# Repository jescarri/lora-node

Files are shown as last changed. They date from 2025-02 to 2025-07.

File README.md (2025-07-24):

# Lora Soil Moisture Sensor



This is a low-power, ESP32-powered LoRa board designed for general purposes. For this project, I used the board with a capacitive soil moisture sensor to monitor my houseplants.

# The build

This is a 4-layer PCB board that features a NICERF RFM95W for the LoRa radio and an ESP-WROOM-32D as the microcontroller. Two XC6220B301MR-G LDOs create two separate power rails at 3.0V.

The first power rail supplies power exclusively to the microcontroller (MCU), while the second rail serves as an instrumentation line that becomes active when the ESP32 wakes up from deep sleep. This rail powers both the radio and the sensors. Additionally, the MAX17048 includes a LiPo fuel gauge.

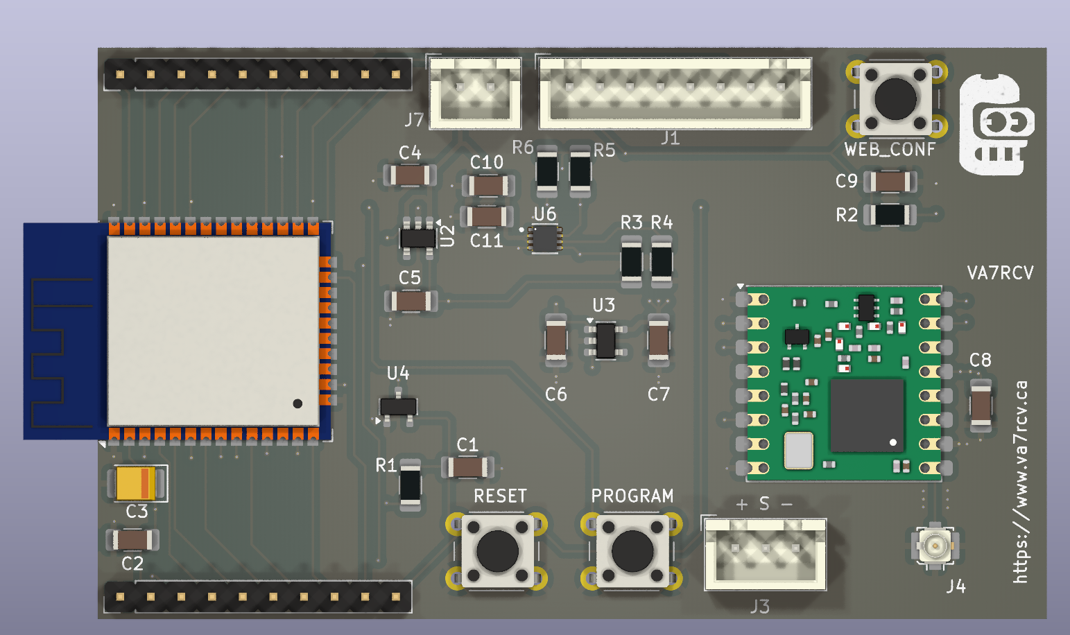
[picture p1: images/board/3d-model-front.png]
Board Front


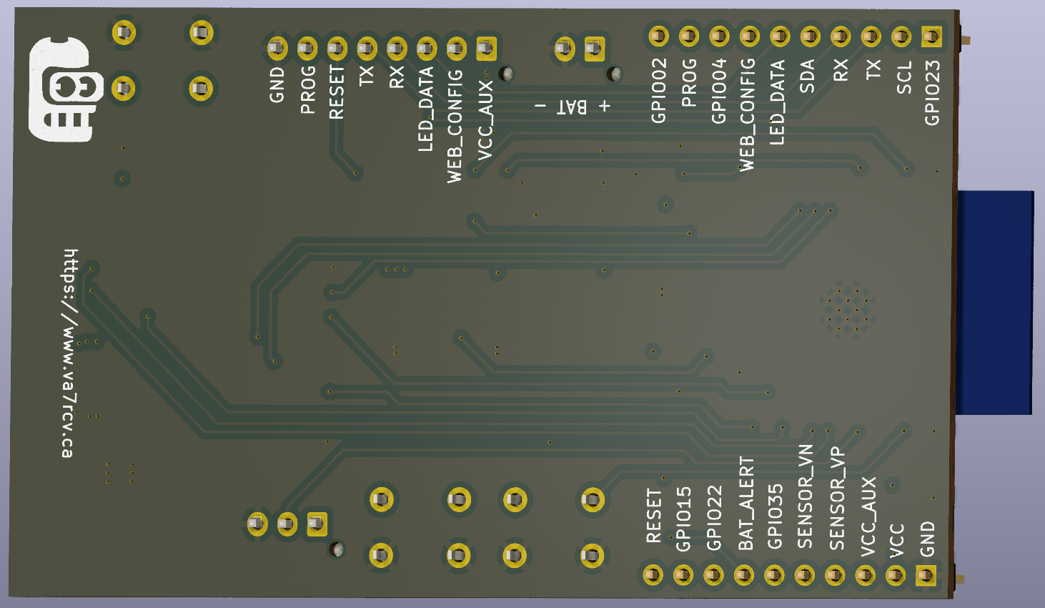
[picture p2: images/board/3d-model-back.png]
Board Back


There's a WS2812B LED that provides feedback to the user.

- Red: The node does not have a valid configuration or is in WebConfig state (AP Mode).

- Green: Node successfully joined TTN after configuration.

- Orange: Error Joining the TTN network.

- Unless the above events happen, the LED remains powered off at all times.

# The Firmware

The Lora deep sleep routines are based on [Andreas Spiess Lora Mailbox with DeepSleep](https://github.com/SensorsIot/MailboxNotifier/tree/main), but instead of using the EEPROM routines to save the LMIC status, I used the [Preferences library](https://docs.espressif.com/projects/arduino-esp32/en/latest/tutorials/preferences.html)

This project uses the ArduinoLMICC library.

This Firmware has a lot of debug code and requires some re-organization it is a PoC and it has been running for about 3 moths without any issue.

ToDo:
----

1. Add downlink capabilities to trigger WiFi join and do OTA.

2. Investigate how to add crypto validation of the firmware.

3. Re organize the code, WiFi menu and config is a mess.

4. Remove debug code.

5. Standardize LED feedback colors.

# Telemetry format

Data is sent to the Things Network using CayenneLPP, This project uses the [electroniccats/CayenneLPP][https://github.com/ElectronicCats/CayenneLPP] implementation, I found this to be the implementation that had extended support for extra data fields.

# Things Network configuration

1. Create an application.

2. Add the Payload Decoder from the (electroniccats/CayenneLPP)[] project.

3. Create an device use: LoRaWAN Specification 1.0.3, RP001 Regional Parameters 1.0.3 revision A

# Build Configuration and Size Optimization

This project uses a single optimized build configuration:

- **ttgo-lora32-v1-release**: Production build with size optimizations (-Os, function/data sections, dead code elimination)

## Size-Saving Tips

1. **String Storage**: Use PROGMEM for string constants to reduce SRAM usage
2. **Conditional Compilation**: Wrap diagnostic code with `#ifdef DEBUG` blocks for development
3. **Compiler Optimization**: Use `-Os`, `-ffunction-sections`, `-fdata-sections`, `-Wl,--gc-sections`
4. **LMIC Debug Level**: Set to 0 for production builds to reduce binary size

## Current Build Size

- **Release Build**: 92.4% Flash usage (1,211,449 bytes) - **90KB reduction achieved**

For detailed build information, see [docs/BUILD.md](docs/BUILD.md).

## Watchdog Management for OTA Updates

The firmware implements comprehensive watchdog timer management and stack overflow prevention to prevent system crashes during OTA (Over-The-Air) firmware updates:

### Watchdog Reset Points

- **WiFi Connection Loop**: Reset every 100ms during WiFi connection attempts (8-second timeout)
- **HTTP Download Loop**: Reset every 1000ms during firmware download (improved from 2000ms)
- **WiFi Test Function**: Reset every 400ms during WiFi connectivity testing
- **OTA Progress Updates**: Watchdog reset occurs with each progress update (every 5 seconds or 50KB chunks)

### Stack Overflow Prevention

To prevent stack canary watchpoint panics that can occur during OTA operations:

- **Heap-Allocated Download Buffer**: Uses `malloc()` to allocate a 2KB download buffer on the heap instead of stack
- **Reduced Buffer Size**: Download buffer reduced from 4KB to 2KB to minimize memory usage
- **Proper Error Cleanup**: All error paths properly free allocated memory with appropriate cleanup
- **Memory Safety**: Buffer is set to `nullptr` after freeing to prevent double-free issues

### Timeout Constants

- `WIFI_CONNECTION_TIMEOUT`: 8000ms (8 seconds) - Maximum time to wait for WiFi connection
- `HTTP_TOTAL_TIMEOUT`: 30000ms (30 seconds) - Total HTTP request timeout for OTA downloads
- `HTTP_CONNECT_TIMEOUT`: 15000ms (15 seconds) - HTTP connection establishment timeout
- `CONNECTIVITY_TEST_TIMEOUT`: 10000ms (10 seconds) - Internet connectivity test timeout
- `WATCHDOG_RESET_INTERVAL_DOWNLOAD`: 1000ms (1 second) - Watchdog reset frequency during download
- `WATCHDOG_RESET_INTERVAL_WIFI_TEST`: 400ms - Watchdog reset frequency during WiFi testing
- `PROGRESS_UPDATE_INTERVAL`: 5000ms (5 seconds) - Progress update and watchdog reset frequency
- `CHUNK_SIZE_THRESHOLD`: 51200 bytes (50KB) - Alternative trigger for progress updates

### HTTPUpdate Library Integration

The OTA system now uses ESP32's built-in HTTPUpdate library for improved reliability:

- **Automatic HTTPS Support**: Handles both HTTP and HTTPS URLs with redirect following
- **MD5 Verification**: Uses HTTPUpdate's native MD5 verification with manual header injection
  - GitHub doesn't provide `x-MD5` headers, so we inject the MD5 from TTN downlink via request callback
  - HTTPUpdate then performs automatic MD5 verification during download
- **Progress Monitoring**: Real-time download progress with watchdog management
- **Error Handling**: Comprehensive error reporting and cleanup
- **Memory Efficiency**: No large buffer allocation - HTTPUpdate handles streaming internally
- **Redirect Support**: Automatic handling of HTTP redirects (strict mode enabled)

### Network Diagnostics

The OTA system includes comprehensive network diagnostics:

- **HTTPS Support**: Automatic detection and handling of HTTPS URLs with certificate validation bypass
- **Timeout Configuration**: Explicit HTTP timeouts prevent indefinite blocking
- **Redirect Handling**: Automatic following of HTTP redirects using HTTPUpdate's built-in support
- **Error Reporting**: Detailed error codes and diagnostic messages for troubleshooting

## Build Commands

- `make release`: Build the main release environment (ttgo-lora32-v1)
- `make minimal`: Build the minimal environment for comparison
- For verbose output, set environment variable: `PLATFORMIO_BUILD_FLAGS=-v`
  
  Example: `PLATFORMIO_BUILD_FLAGS=-v make release`

# Node Provisioning

1. Build the firmware and upload it to the board.

2. The board will enter in config mode, and access point named lora-node will be created.

3. Connect to the wifi and open 192.168.4.1 in your web browser, and configure the node paramethers.

3.1 Provisioning Menu:

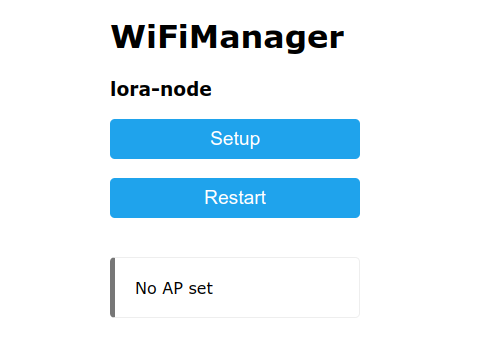
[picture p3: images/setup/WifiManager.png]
Wifi Manager WiFi Manager


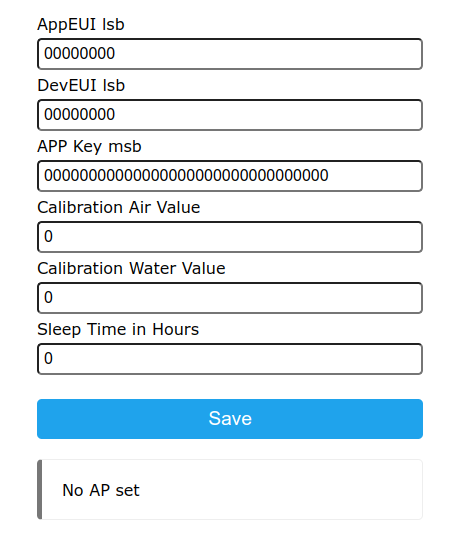
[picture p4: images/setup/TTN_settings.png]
TTN and Calibration Settings


# Soil moisture sensor calibration

Once the node is provisioned, and joined your applicaton in The things network.

1. Rested the board and measure the reading in Air-Free / Dry conditions and record raw sensore reading, you can see it in the serial console or in TTN.

2. Submerge the soil sensor in water and reset the board and record the raw sensor reading.

3. Press the WEB_CONF button and reset the board leaving the WEB_CONF button pressed, the board will enter in configuration mode and a WiFi Access point named lora-node will appear, connect to it and go to 192.168.4.1 in your browser.

4. Input the Free-Air and Water values recorded in steps 1 and 2.

Calibration is done.

# Home Assistant Integration

You need to configure an MQTT bridge between TTN and your Local MQTT server, there's plenty of information on how to do this online.

The Node-Red folder has Auto-Discovery, that you can use as a starting point for MQTT auto discovery.

There's also a Telegram bot that will notify you when the Node has not been seen in 24 Hours.

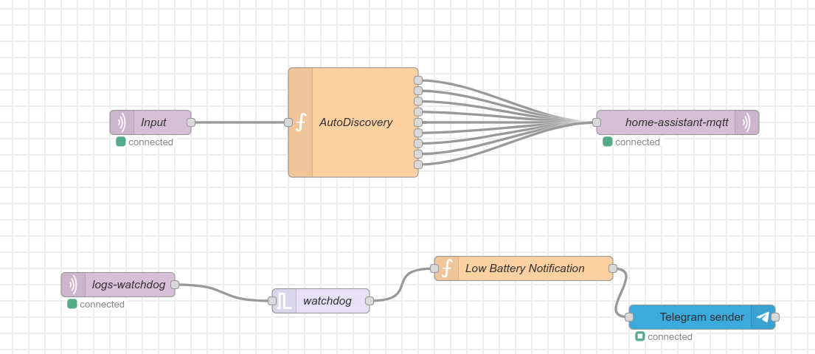
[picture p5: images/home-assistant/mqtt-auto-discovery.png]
MQTT Autodiscovery Home Assistant MQTT Autodiscovery


MQTT Device
-----------

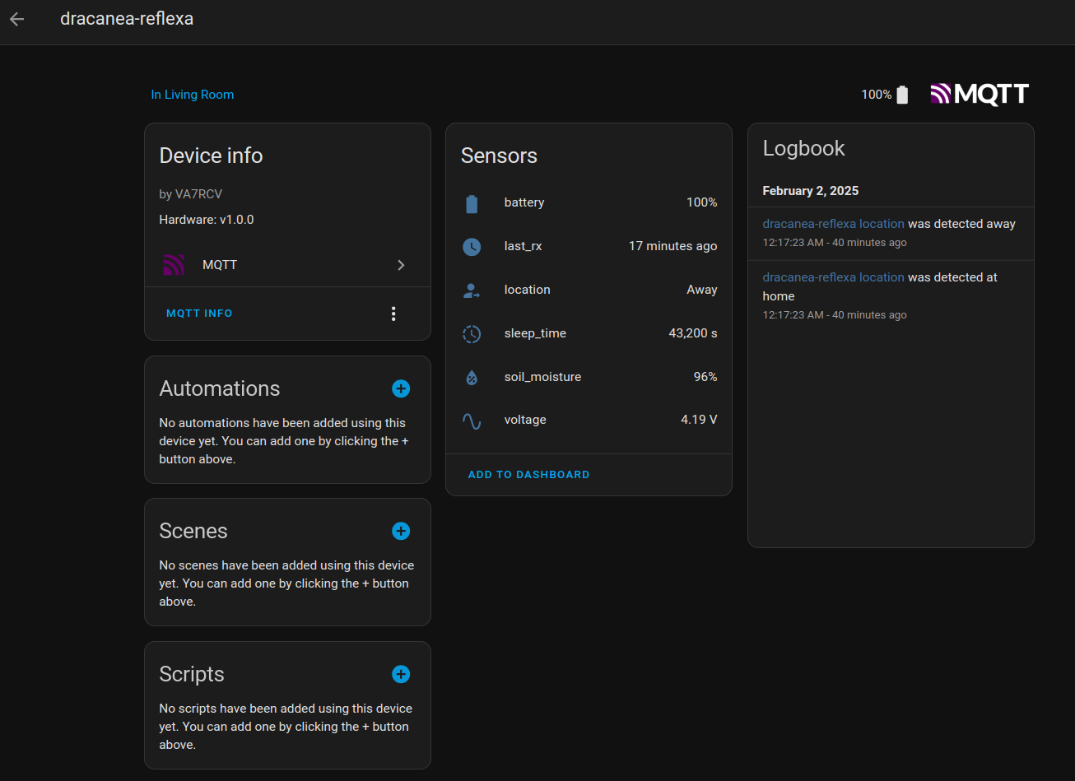
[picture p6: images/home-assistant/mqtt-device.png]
MQTT Device


Home assistant Panel
------------------

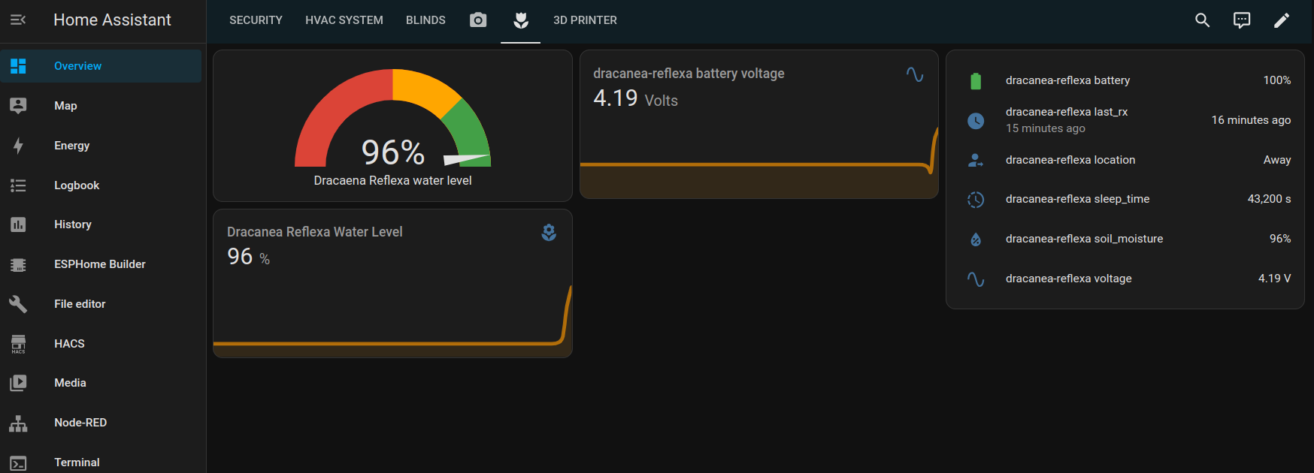
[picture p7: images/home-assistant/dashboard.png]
HA Panel


# Enclosure

Under the enclosure directory you will find STL files to print the sensor enclosure, you can 3D print the board holder and it will fit a 2.5 Inches PVC Pipe ( Internal Diameter ).

There's also a 3D model of a pipe you can print for indoors applications.

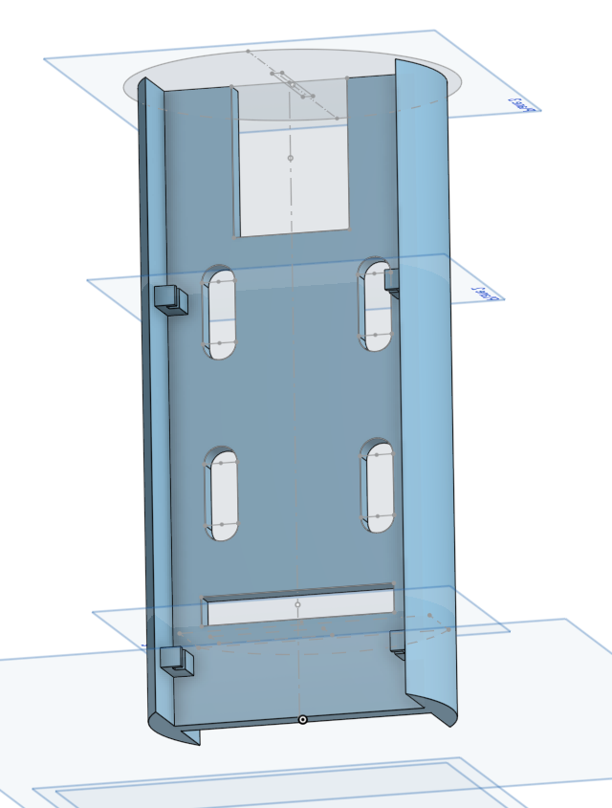
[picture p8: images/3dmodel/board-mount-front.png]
Board Holder


# Final Product

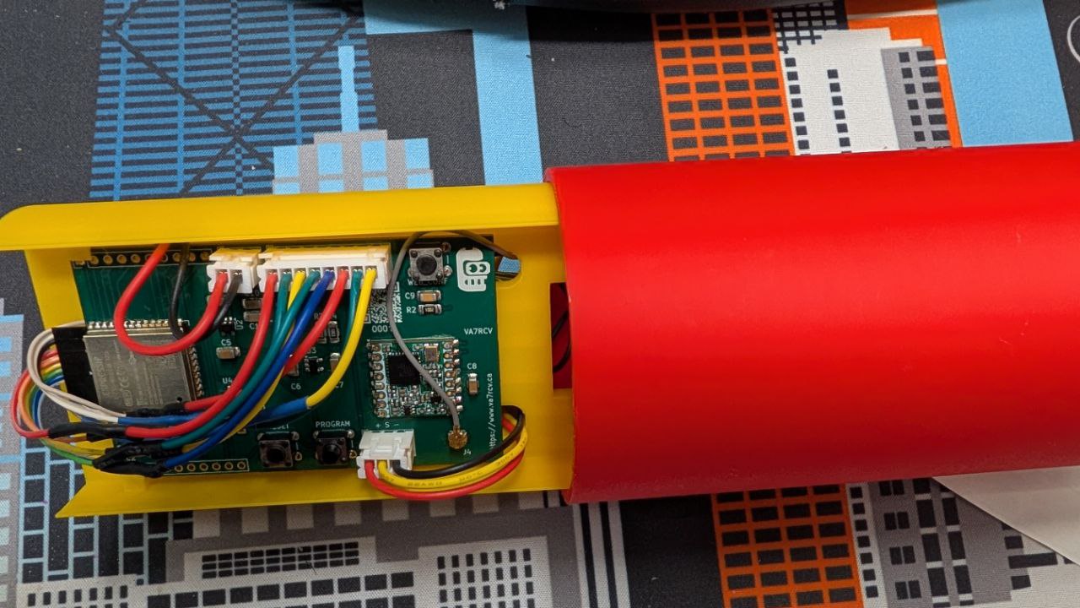
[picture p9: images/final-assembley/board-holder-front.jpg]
Board Front


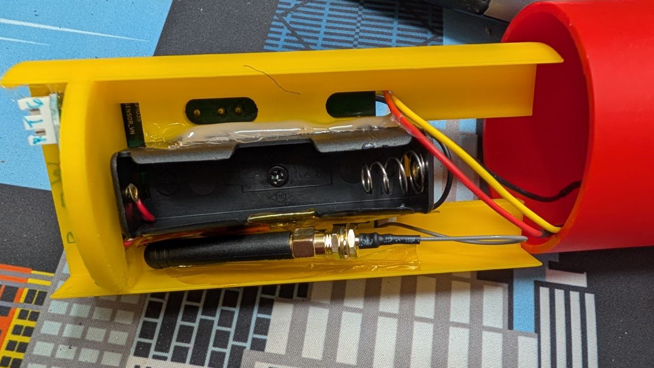
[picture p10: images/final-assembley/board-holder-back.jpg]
Board Back Board Holder Back


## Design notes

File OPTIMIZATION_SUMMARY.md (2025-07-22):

# String Storage and Logging Optimizations

## Overview
This document summarizes the string storage and logging optimizations applied to the LoRa sensor codebase to reduce memory usage and improve performance.

## 1. PROGMEM String Constants

### Files Modified:
- `src/main.cpp`
- `src/lorawan.cpp`

### Changes Made:
- Added `const char PROGMEM` declarations for frequently used string literals
- Replaced direct string literals with `FPSTR()` macro calls
- Used `F()` macro for inline string literals in Serial.print() calls

### Examples:
```cpp
// Before:
Serial.println("LIPO GAUGE FOUND");

// After:
const char PROGMEM msg_lipo_gauge_found[] = "LIPO GAUGE FOUND";
Serial.println(FPSTR(msg_lipo_gauge_found));

// Or alternatively:
Serial.println(F("LIPO GAUGE FOUND"));
```

### Benefits:
- Strings are stored in program memory (PROGMEM) instead of RAM
- Reduces SRAM usage during runtime
- Improves overall memory efficiency

## 2. Conditional Debug Compilation

### Files Modified:
- `platformio.ini`
- `src/main.cpp`
- `src/lorawan.cpp`

### Changes Made:
- Added conditional compilation using `#ifdef DEBUG` blocks for development diagnostics
- Applied conditional compilation to verbose logging functions

### Examples:
```cpp
// Before:
Serial.println("Debug message");

// After:
#ifdef DEBUG
Serial.println("Debug message");
#endif
```

### Benefits:
- Diagnostic logs can be selectively compiled during development
- Production builds have reduced code size
- Maintains debugging capability when needed for development

## 3. Optimized Logging Functions

### Changes Made:
- Modified `LoraWANDebug()` function to only execute in debug builds
- Replaced `Serial.printf()` with multiple `Serial.print()` calls for PROGMEM compatibility
- Optimized sensor reading debug output

### Benefits:
- Reduced flash memory usage in production builds
- Maintained debugging capabilities for development
- Improved code readability and maintainability

## 4. Build Size Results

### Release Build (ttgo-lora32-v1):
- Text: 1,069,553 bytes
- Data: 252,209 bytes
- BSS: 29,536 bytes
- **Total: 1,351,298 bytes**

### Optimizations Applied:
1. **String Storage**: Moved string constants to PROGMEM
2. **Conditional Compilation**: Added DEBUG flag for optional logging
3. **Memory Efficiency**: Reduced SRAM usage by storing strings in flash

## 5. Build Configuration

### Environment:
- **ttgo-lora32-v1-release**: Optimized production build with size optimizations

### Compilation Flags:
- `-Os`: Optimize for size
- `-ffunction-sections`: Place functions in separate sections
- `-fdata-sections`: Place data in separate sections
- `-Wl,--gc-sections`: Remove unused sections during linking

## 6. Testing

### Verification Steps:
1. ✅ Release build compiles successfully
2. ✅ String optimizations applied correctly
3. ✅ Conditional compilation works as expected
4. ✅ Memory usage reduced without functionality loss

## Summary

The optimizations successfully:
- Reduced memory usage by moving strings to PROGMEM
- Implemented conditional compilation for development diagnostics
- Maintained code functionality and readability
- Consolidated to a single optimized build configuration

These optimizations help improve the performance and memory efficiency of the LoRa sensor device, especially important for embedded systems with limited resources.

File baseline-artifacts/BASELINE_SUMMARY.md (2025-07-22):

# Size-Tracking Baseline - Task Completion Summary

## ✅ Task Completed Successfully

This document summarizes the completion of **Step 1: Create a size-tracking baseline** from the project optimization plan.

## What Was Accomplished

### 1. ✅ Clean Build Locally
- Performed a clean build using `pio run -v > build.log`
- Captured detailed build output with memory usage information
- Recorded current memory usage:
  - **RAM**: 17.3% (56,560 bytes used / 327,680 bytes total)
  - **Flash**: 99.3% (1,302,037 bytes used / 1,310,720 bytes total)

### 2. ✅ Captured .elf and .map Files
- Generated and archived `firmware.elf` (20.2 MB)
- Generated and archived `firmware.map` (13.8 MB)
- Both files are now preserved in the `baseline-artifacts/` directory

### 3. ✅ Recorded Flash/RAM Usage
- Created comprehensive memory usage summary in `memory-usage-summary.txt`
- Detailed build log with verbose output shows memory sections
- Identified that Flash memory is nearly full (99.3%), highlighting optimization need

### 4. ✅ GitHub CI Runner Setup
- Created `.github/workflows/size-baseline.yml` workflow
- Configured to trigger on pushes to `size-baseline` branch
- Will capture the same artifacts on GitHub Actions ubuntu-latest runners
- CI artifacts will be uploaded with 90-day retention

### 5. ✅ Committed to size-baseline Branch
- Created new branch `size-baseline` from current state
- Committed all baseline artifacts:
  - `firmware.elf` - Complete firmware binary
  - `firmware.map` - Memory map for detailed analysis
  - `build.log` - Verbose build output (forced add despite .gitignore)
  - `memory-usage-summary.txt` - Human-readable summary
- Pushed branch to origin to trigger CI workflow

## Files Archived for Later Diffing

| File | Size | Purpose |
|---|---|---|
| `firmware.elf` | 20.2 MB | Complete firmware binary with debug symbols |
| `firmware.map` | 13.8 MB | Memory map showing symbol locations and sizes |
| `build.log` | 159 KB | Verbose build output with memory section details |
| `memory-usage-summary.txt` | 856 B | Human-readable summary of memory usage |

## Critical Measurements Captured

- **Current RAM Usage**: 56,560 bytes (17.3% of 327,680 bytes)
- **Current Flash Usage**: 1,302,037 bytes (99.3% of 1,310,720 bytes)
- **Available Flash**: Only 8,683 bytes remaining (0.7%)
- **Build Environment**: ttgo-lora32-v1 (ESP32)
- **Git Commit**: faae3e0d8deeaebde633c6fe64fd03a4eff1e3f5

## Next Steps

This baseline provides the foundation for objective measurement of all future optimization steps. Each subsequent step can now be measured against this baseline using:

1. **Memory Usage Comparison**: Compare RAM/Flash percentages
2. **Map File Diffing**: Use `firmware.map` to identify which symbols/sections changed
3. **Build Log Analysis**: Compare verbose build outputs to track compilation changes
4. **Automated CI Tracking**: GitHub Actions will capture equivalent baselines

## Usage Instructions

To compare future builds against this baseline:

```bash
# Compare memory usage
grep "RAM:\|Flash:" baseline-artifacts/build.log
grep "RAM:\|Flash:" current-build.log

# Diff memory maps
diff baseline-artifacts/firmware.map .pio/build/ttgo-lora32-v1/firmware.map

# Compare ELF files
size baseline-artifacts/firmware.elf
size .pio/build/ttgo-lora32-v1/firmware.elf
```

The size-baseline branch is now ready for use as the reference point for all future optimization measurements.

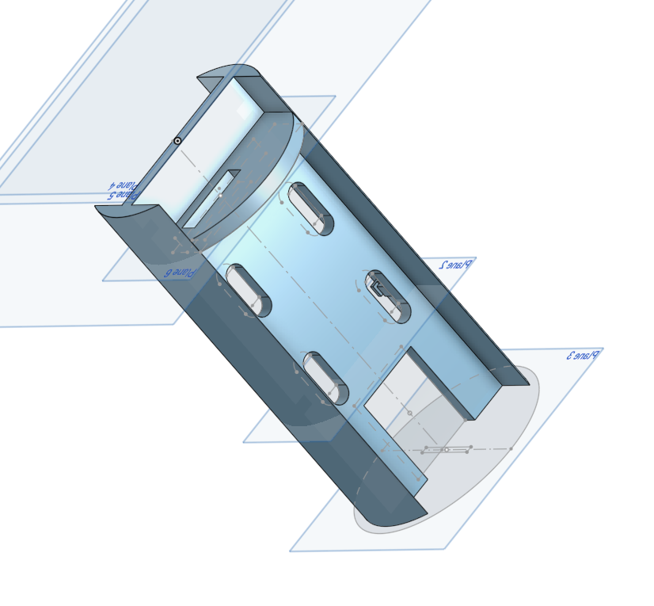
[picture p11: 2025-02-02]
images/3dmodel/board-mount-side.png

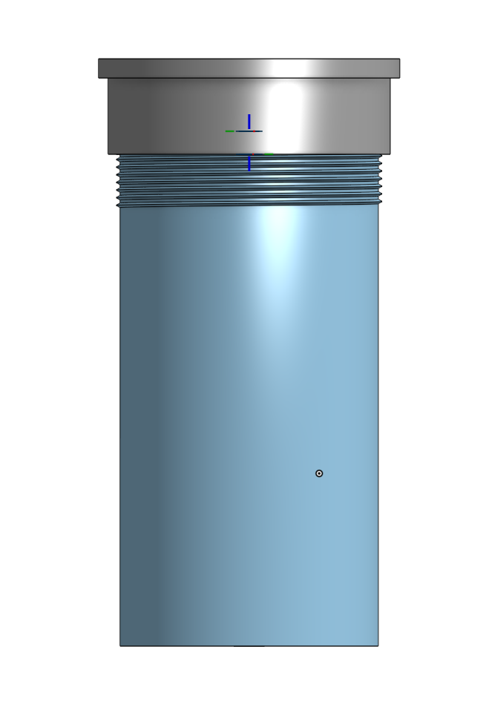
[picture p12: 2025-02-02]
images/3dmodel/tube.png

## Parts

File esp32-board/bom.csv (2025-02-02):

Reference | Value | Datasheet | Footprint | Qty | DNP
C1,C9 | 1uF | ~ | Capacitor_SMD:C_1206_3216Metric_Pad1.33x1.80mm_HandSolder | 2
C2,C10,C11 | 100nF | ~ | Capacitor_SMD:C_1206_3216Metric_Pad1.33x1.80mm_HandSolder | 3
C3 | 22uF | ~ | Capacitor_Tantalum_SMD:CP_EIA-3528-21_Kemet-B_Pad1.50x2.35mm_HandSolder | 1
C4,C6,C8 | 10uF | ~ | Capacitor_SMD:C_1206_3216Metric_Pad1.33x1.80mm_HandSolder | 3
C5,C7 | 4.7uF | ~ | Capacitor_SMD:C_1206_3216Metric_Pad1.33x1.80mm_HandSolder | 2
J1 | remote_header | ~ | Connector_JST:JST_XH_B8B-XH-AM_1x08_P2.50mm_Vertical | 1
J3 | SOIL_SENSOR | ~ | Connector_JST:JST_XH_B3B-XH-AM_1x03_P2.50mm_Vertical | 1
J4 | ANT | ~ | Connector_Coaxial:U.FL_Molex_MCRF_73412-0110_Vertical | 1
J5,J6 | Conn_01x10_Pin | ~ | Connector_PinHeader_2.54mm:PinHeader_1x10_P2.54mm_Vertical | 2
J7 | Battery | ~ | Connector_JST:JST_XH_B2B-XH-AM_1x02_P2.50mm_Vertical | 1
R1,R2,R3 | 10K | ~ | Resistor_SMD:R_1206_3216Metric_Pad1.30x1.75mm_HandSolder | 3
R4 | 100k | ~ | Resistor_SMD:R_1206_3216Metric_Pad1.30x1.75mm_HandSolder | 1
R5,R6 | 2.2K | ~ | Resistor_SMD:R_1206_3216Metric_Pad1.30x1.75mm_HandSolder | 2
RESET1 | RESET | ~ | Button_Switch_THT:SW_PUSH_6mm_H5mm | 1
SW2 | ESP Program | ~ | Button_Switch_THT:SW_PUSH_6mm_H5mm | 1
SW3 | WEB_CONF | ~ | Button_Switch_THT:SW_PUSH_6mm_H5mm | 1
U1 | ESP32-WROOM-32D | https://www.espressif.com/sites/default/files/documentation/esp32-wroom-32d_esp32-wroom-32u_datasheet_en.pdf | RF_Module:ESP32-WROOM-32 | 1
U2,U3 | XC6220B331MR | https://www.torexsemi.com/file/xc6220/XC6220.pdf | Package_TO_SOT_SMD:SOT-23-5 | 2
U4 | TPS3839DBZ | http://www.ti.com/lit/ds/sbvs193d/sbvs193d.pdf | Package_TO_SOT_SMD:SOT-23 | 1
U5 | RFM95W-915S2 | https://www.hoperf.com/data/upload/portal/20181127/5bfcbea20e9ef.pdf | RF_Module:HOPERF_RFM9XW_SMD | 1
U6 | MAX17048G_T10 |  | MAX17048G+T10:SON50P200X200X80-9N | 1

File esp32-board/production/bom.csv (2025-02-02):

Designator | Footprint | Quantity | Value | LCSC Part #
C1, C9 | 1206 | 2 | 1uF
C10, C11, C2 | 1206 | 3 | 100nF
C3 | CP_EIA-3528-21_Kemet-B_Pad1.50x2.35mm_HandSolder | 1 | 22uF
C4, C6, C8 | 1206 | 3 | 10uF
C5, C7 | 1206 | 2 | 4.7uF
J1 | JST_XH_B8B-XH-AM_1x08_P2.50mm_Vertical | 1 | remote_header
J3 | JST_XH_B3B-XH-AM_1x03_P2.50mm_Vertical | 1 | SOIL_SENSOR
J4 | U.FL_Molex_MCRF_73412-0110_Vertical | 1 | ANT
J5, J6 | PinHeader_1x10_P2.54mm_Vertical | 2 | Conn_01x10_Pin
J7 | JST_XH_B2B-XH-AM_1x02_P2.50mm_Vertical | 1 | Battery
R1, R2, R3 | 1206 | 3 | 10K
R4 | 1206 | 1 | 100k
R5, R6 | 1206 | 2 | 2.2K
RESET1 | SW_PUSH_6mm_H5mm | 1 | RESET
SW2 | SW_PUSH_6mm_H5mm | 1 | ESP Program
SW3 | SW_PUSH_6mm_H5mm | 1 | WEB_CONF
U1 | ESP32-WROOM-32 | 1 | ESP32-WROOM-32D
U2, U3 | SOT-23-5 | 2 | XC6220B331MR
U4 | SOT-23 | 1 | TPS3839DBZ
U5 | HOPERF_RFM9XW_SMD | 1 | RFM95W-915S2
U6 | SON50P200X200X80-9N | 1 | MAX17048G_T10

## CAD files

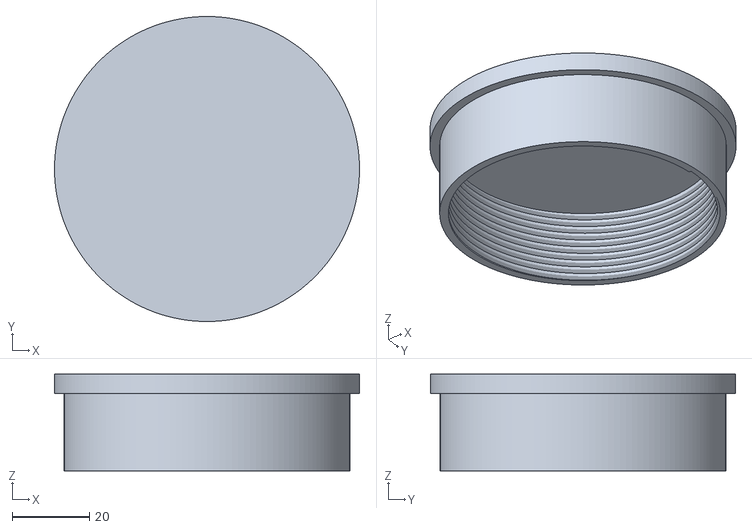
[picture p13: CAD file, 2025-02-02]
enclosure/cap.stl
79.0 x 79.0 x 25.0

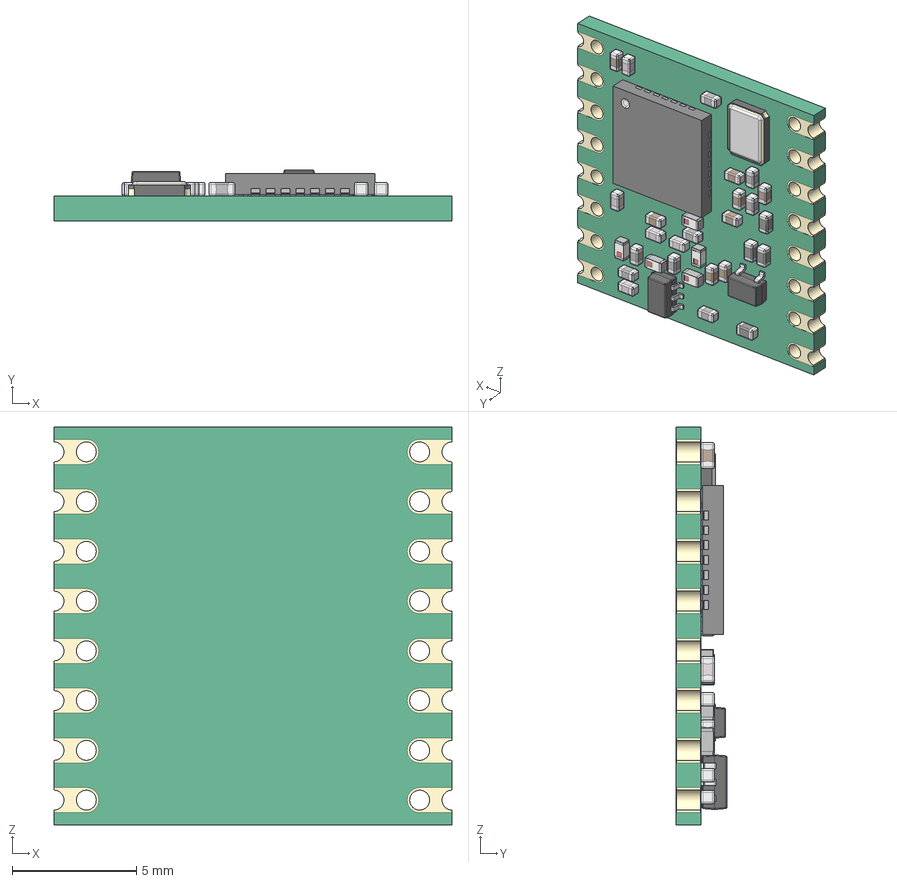
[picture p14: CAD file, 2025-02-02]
esp32-board/models/RFM95/RFM95 LoRa v15.step
16.0 x 2.04 x 16.0 mm
QFN 28
SMD Crystal
CAP 0403 x 8
CAP Ceramic 0403 x 8
Res 0403 x 4
CAP ML 0403 x 5
SOT-323
Inductor SMD 0403 x 5
SOT-363

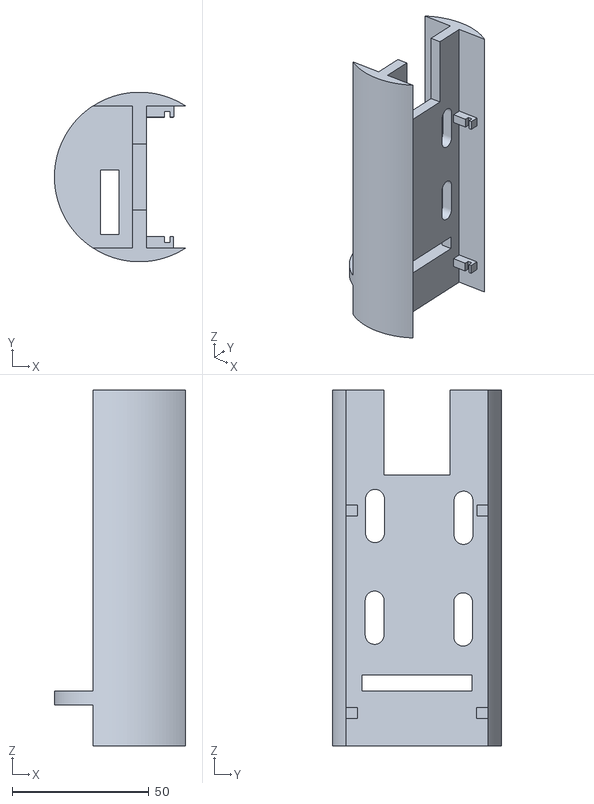
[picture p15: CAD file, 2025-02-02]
enclosure/board-mount.stl
47.9 x 61.9 x 130.0

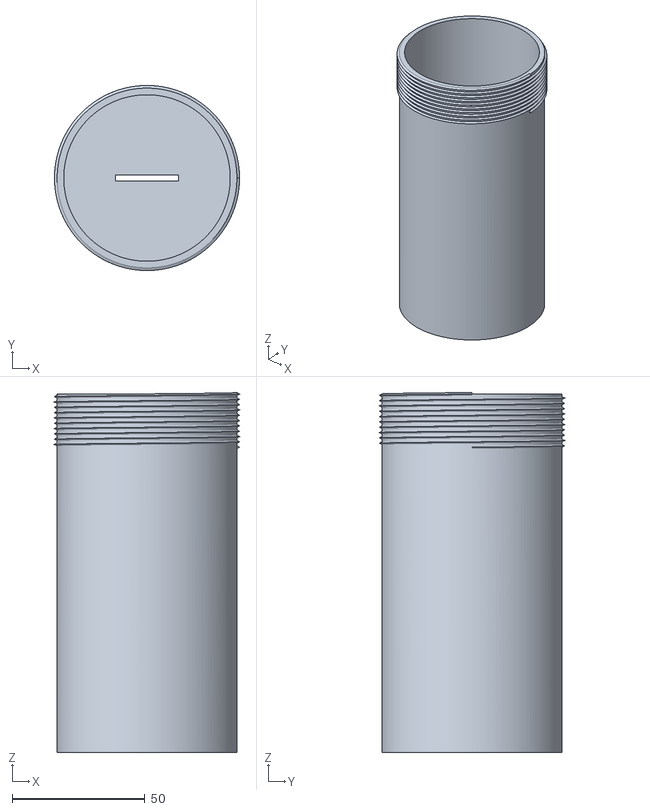
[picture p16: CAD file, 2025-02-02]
enclosure/tube.stl
69.7 x 69.7 x 135.6

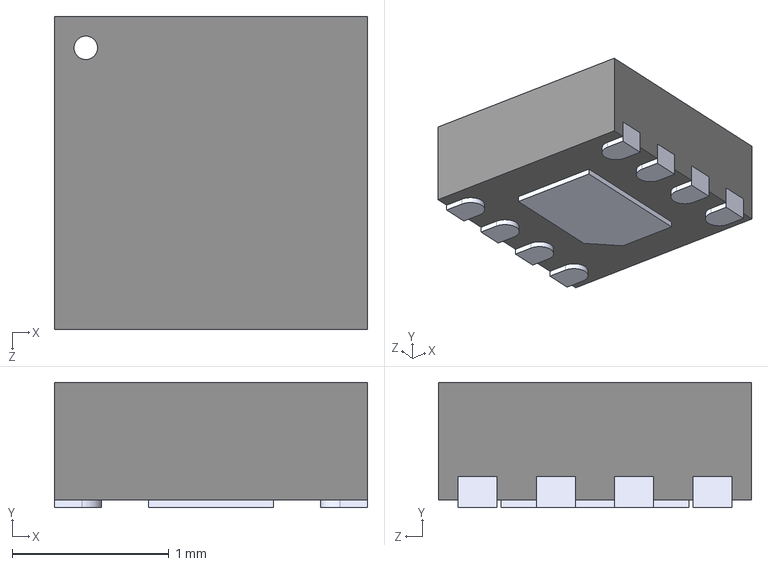
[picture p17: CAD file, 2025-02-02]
esp32-board/models/MAX17048G+T10/MAX17048G_T10.step
2.00 x 0.8 x 2.00 mm

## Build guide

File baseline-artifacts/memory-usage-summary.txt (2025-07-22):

Size Tracking Baseline - Memory Usage Summary
=============================================

Build Environment: ttgo-lora32-v1
Build Date: Wed 16 Jul 2025 12:56:56 PM PDT
Git Branch: size-baseline
Git Commit: faae3e0d8deeaebde633c6fe64fd03a4eff1e3f5

MEMORY USAGE:
- RAM:   17.3% (used 56,560 bytes from 327,680 bytes)
- Flash: 99.3% (used 1,302,037 bytes from 1,310,720 bytes)

AVAILABLE MEMORY:
- Free RAM: 271,120 bytes (82.7%)
- Free Flash: 8,683 bytes (0.7%)

FILES ARCHIVED:
- firmware.elf: Complete firmware binary
- firmware.map: Memory map file for analysis
- build.log: Verbose build output with detailed memory sections

USAGE:
This baseline can be used to compare memory usage changes in future builds.
Use the firmware.map file to analyze memory layout changes.
Compare build.log files to identify which components contribute to size changes.

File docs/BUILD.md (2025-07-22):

# Build Documentation

This document provides instructions and tips for building the firmware of the LoRa Soil Moisture Sensor project.

## Build Environment

- **ttgo-lora32-v1-release**: Production build with optimizations for size.

## Build Size Optimization Tips

1. **String Storage**: Store string constants in PROGMEM to reduce SRAM usage.
2. **Conditional Compilation**: Use DEBUG flags during development for diagnostic information.
3. **Compiler Flags**: Use `-Os`, `-ffunction-sections`, `-fdata-sections`, `-Wl,--gc-sections` to optimize for size.

## Current Build Size

- **Release Build**:
  - RAM: 16.8% (used 55,084 bytes from 327,680 bytes)
  - Flash: 92.4% (used 1,211,449 bytes from 1,310,720 bytes)

## Size Reduction

- **Before Optimization**:
  - Flash: 99.3% (used 1,302,037 bytes)

- **After Optimization**:
  - Flash: 92.4% (used 1,211,449 bytes)

- **Total Reduction**: 90,588 bytes (~14 KB)

## Building the Firmware

To build the firmware, use the following command:

```bash
pio run --environment ttgo-lora32-v1-release
```

## Skipping Size Checks

For development purposes, you may skip the size check:
```
extra_scripts = pre:skip_size_check.py
```

This concludes the build documentation.

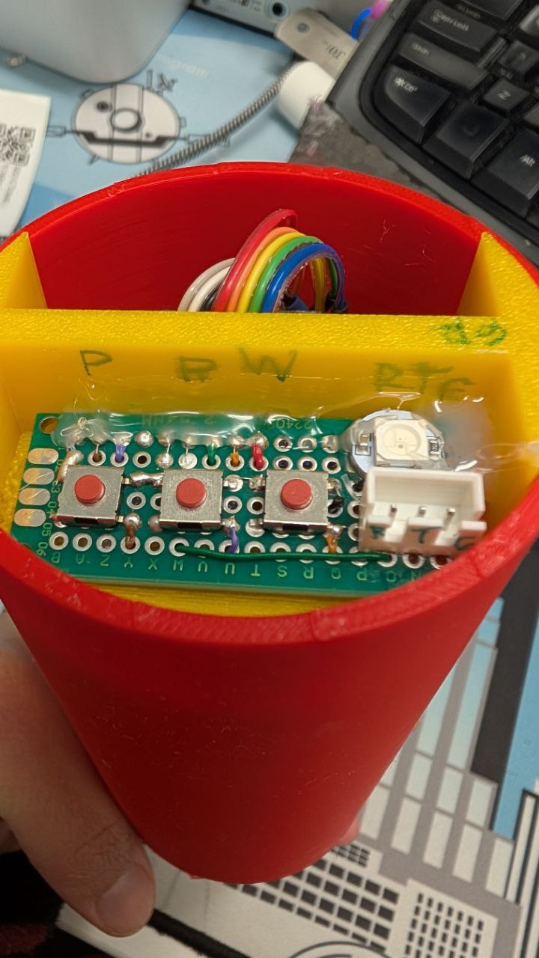
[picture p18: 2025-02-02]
images/final-assembley/control-board.jpg

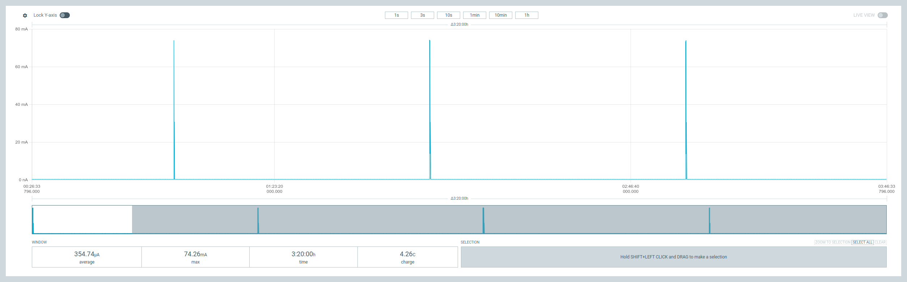
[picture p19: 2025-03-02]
power-profile/v1.0.0/3hours_of_operation.png

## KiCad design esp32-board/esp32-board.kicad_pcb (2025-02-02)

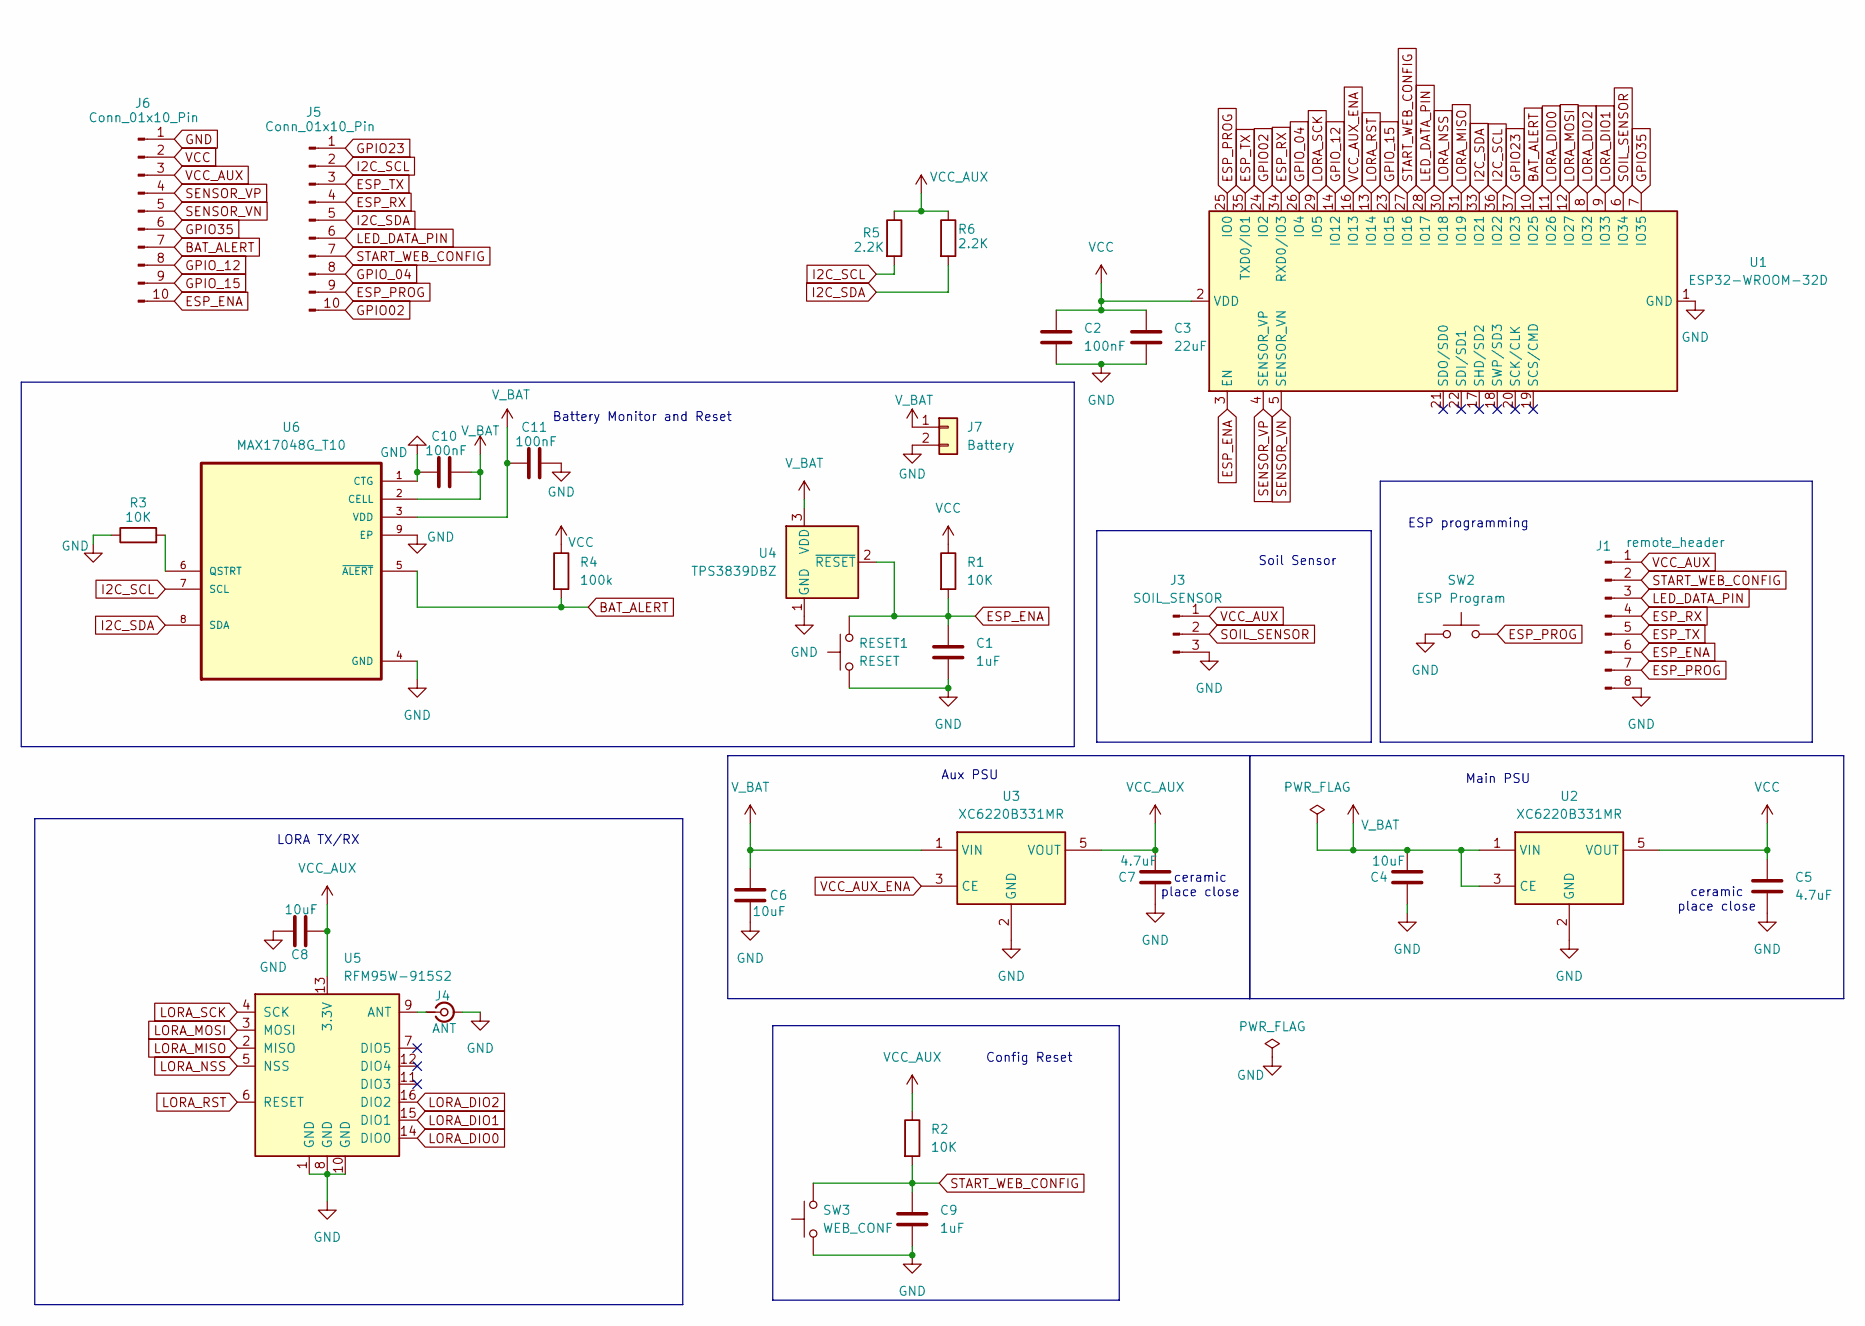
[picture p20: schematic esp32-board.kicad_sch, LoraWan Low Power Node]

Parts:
C1, C9: 1uF; C_1206_3216Metric_Pad1.33x1.80mm_HandSolder
C2, C10, C11: 100nF; C_1206_3216Metric_Pad1.33x1.80mm_HandSolder
C3: 22uF; CP_EIA-3528-21_Kemet-B_Pad1.50x2.35mm_HandSolder
C4, C6, C8: 10uF; C_1206_3216Metric_Pad1.33x1.80mm_HandSolder
C5, C7: 4.7uF; C_1206_3216Metric_Pad1.33x1.80mm_HandSolder
J1: remote_header; JST_XH_B8B-XH-AM_1x08_P2.50mm_Vertical
J3: SOIL_SENSOR; JST_XH_B3B-XH-AM_1x03_P2.50mm_Vertical
J4: ANT; U.FL_Molex_MCRF_73412-0110_Vertical
J5, J6: Conn_01x10_Pin; PinHeader_1x10_P2.54mm_Vertical
J7: Battery; JST_XH_B2B-XH-AM_1x02_P2.50mm_Vertical
R1, R2, R3: 10K; R_1206_3216Metric_Pad1.30x1.75mm_HandSolder
R4: 100k; R_1206_3216Metric_Pad1.30x1.75mm_HandSolder
R5, R6: 2.2K; R_1206_3216Metric_Pad1.30x1.75mm_HandSolder
RESET1: RESET; SW_PUSH_6mm_H5mm
SW2: ESP Program; SW_PUSH_6mm_H5mm
SW3: WEB_CONF; SW_PUSH_6mm_H5mm
U1: ESP32-WROOM-32D; ESP32-WROOM-32
U2, U3: XC6220B331MR; SOT-23-5
U4: TPS3839DBZ; SOT-23
U5: RFM95W-915S2; HOPERF_RFM9XW_SMD
U6: MAX17048G_T10; SON50P200X200X80-9N

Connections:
BAT_ALERT: J6.7, R4.2, U1.10 (IO25), U6.5 (~ALERT)
ESP_ENA: C1.1, J1.6, J6.10, R1.2, RESET1.2, U1.3 (EN), U4.2 (~RESET)
ESP_PROG: J1.7, J5.9, SW2.2, U1.25 (IO0)
ESP_RX: J1.4, J5.4, U1.34 (RXD0/IO3)
ESP_TX: J1.5, J5.3, U1.35 (TXD0/IO1)
GND: C1.2, C2.2, C3.2, C4.2, C5.2, C6.1, C7.2, C8.1, C9.2, C10.1, C11.2, J1.8, J3.3, J4.2 (Ext), J6.1, J7.2, R3.1, RESET1.1, SW2.1, SW3.1, U1.1 (GND), U1.15 (GND), U1.38 (GND), U1.39 (GND), U2.2 (GND), U3.2 (GND), U4.1 (GND), U5.1 (GND), U5.8 (GND), U5.10 (GND), U6.1 (CTG), U6.4 (GND), U6.9 (EP)
GPIO02: J5.10, U1.24 (IO2)
GPIO23: J5.1, U1.37 (IO23)
GPIO35: J6.6, U1.7 (IO35)
GPIO_04: J5.8, U1.26 (IO4)
GPIO_12: J6.8, U1.14 (IO12)
GPIO_15: J6.9, U1.23 (IO15)
I2C_SCL: J5.2, R5.2, U1.36 (IO22), U6.7 (SCL)
I2C_SDA: J5.5, R6.2, U1.33 (IO21), U6.8 (SDA)
LED_DATA_PIN: J1.3, J5.6, U1.28 (IO17)
LORA_DIO0: U1.11 (IO26), U5.14 (DIO0)
LORA_DIO1: U1.9 (IO33), U5.15 (DIO1)
LORA_DIO2: U1.8 (IO32), U5.16 (DIO2)
LORA_MISO: U1.31 (IO19), U5.2 (MISO)
LORA_MOSI: U1.12 (IO27), U5.3 (MOSI)
LORA_NSS: U1.30 (IO18), U5.5 (NSS)
LORA_RST: U1.13 (IO14), U5.6 (RESET)
LORA_SCK: U1.29 (IO5), U5.4 (SCK)
unnamed: J4.1 (In), U5.9 (ANT)
unnamed: R3.2, U6.6 (QSTRT)
SENSOR_VN: J6.5, U1.5 (SENSOR_VN)
SENSOR_VP: J6.4, U1.4 (SENSOR_VP)
SOIL_SENSOR: J3.2, U1.6 (IO34)
START_WEB_CONFIG: C9.1, J1.2, J5.7, R2.2, SW3.2, U1.27 (IO16)
VCC: C2.1, C3.1, C5.1, J6.2, R1.1, R4.1, U1.2 (VDD), U2.5 (VOUT)
VCC_AUX: C7.1, C8.2, J1.1, J3.1, J6.3, R2.1, R5.1, R6.1, U3.5 (VOUT), U5.13 (3.3V)
VCC_AUX_ENA: U1.16 (IO13), U3.3 (CE)
V_BAT: C4.1, C6.2, C10.2, C11.1, J7.1, U2.1 (VIN), U2.3 (CE), U3.1 (VIN), U4.3 (VDD), U6.2 (CELL), U6.3 (VDD)

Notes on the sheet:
ceramic place close
Config Reset
LORA TX/RX
Soil Sensor
ESP programming
Main PSU
Battery Monitor and Reset
Aux PSU

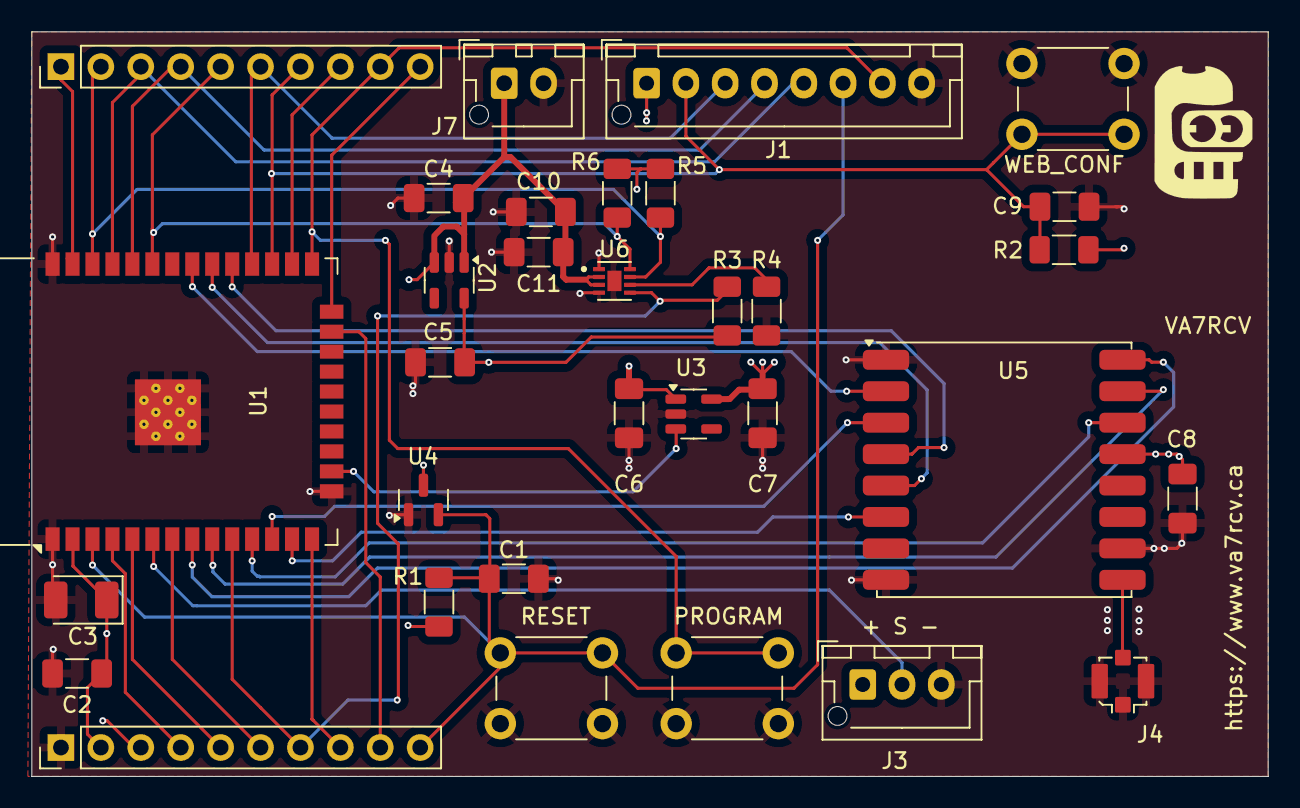
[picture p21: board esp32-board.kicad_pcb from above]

Board: 4 copper layers, 78.7 x 47.4 mm, 32 parts (0 on the bottom side), 33 nets.

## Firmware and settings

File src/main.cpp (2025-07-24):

#include "WiFi.h"
#include "driver/adc.h"

#include <lmic.h>

#include "esp_bt.h"
#include "esp_wifi.h"

#include "esp_sleep.h"
#include "lorawan.hpp"
#include "lorawan_settings.hpp"
#include "menu.hpp"
#include "version.hpp"
#include "ota.hpp"
#include <array>
#include <Adafruit_MAX1704X.h>
#include <FastLED.h>
#include <Wire.h>
#include <hal/hal.h>

// PROGMEM string constants
const char PROGMEM msg_lipo_gauge_found[]    = "LIPO GAUGE FOUND";
const char PROGMEM msg_no_max14048[]         = "No MAX14048 found";
const char PROGMEM msg_lmic_config_present[] = "LMIC CONFIG Present: ";
const char PROGMEM msg_webconf_status[]      = "Webconf status: ";
const char PROGMEM msg_otaa_config_done[]    = "otaa_config_done: ";
const char PROGMEM msg_sleeping_for[]        = "Sleeping for: ";
const char PROGMEM msg_seconds[]             = " seconds";
const char PROGMEM msg_lmic_data_found[]     = "LMIC Data found";
const char PROGMEM msg_can_go_sleep[]        = "Can go sleep ";
const char PROGMEM msg_cannot_sleep[]        = "Cannot sleep ";
const char PROGMEM msg_time_critical_jobs[]  = "TimeCriticalJobs: ";
const char PROGMEM msg_runtime[]             = "Runtime: ";
const char PROGMEM msg_going_to_deepsleep[]  = "Going to DeepSleep for: ";
const char PROGMEM msg_go_deepsleep[]        = "Go DeepSleep";
const char PROGMEM msg_ota_in_progress[]     = "OTA in progress - preventing deep sleep";
const char PROGMEM msg_waiting_for_ota[]     = "Waiting for OTA to complete...";

constexpr int VCC_ENA_PIN                   = 13;
constexpr int START_WEB_CONFIG_PIN          = 16;
constexpr int NUM_LEDS                      = 1;
constexpr int LED_DATA_PIN                  = 17;
constexpr unsigned long long uS_TO_S_FACTOR = 1000000ULL;

lmic_t SETTINGS_LMIC;
CayenneLPP lpp(MAX_PAYLOAD_SIZE);
Adafruit_MAX17048 maxlipo;
CRGB leds[NUM_LEDS];
bool maxLipoFound = false;

// Active in LOW, normal operation is HIGH
bool startWebConfig = false;

void PrintRuntime();
void GoDeepSleep();
void ReadSensors();

volatile bool enableSleep_ = true;
unsigned long entry;

osjob_t sendjob;

const lmic_pinmap lmic_pins = {
    .nss            = config::PinLmicNss,
    .rxtx           = LMIC_UNUSED_PIN,
    .rst            = config::PinLmicRst,
    .dio            = {config::PinLmicDio0, config::PinLmicDio1, config::PinLmicDio2},
    .rxtx_rx_active = 0,
    .spi_freq       = 8000000,
};

static constexpr std::array<gpio_num_t, 12> AUX_PINS = {
    /* LoRa radio (SX127x) */
    GPIO_NUM_5,         // SS  (leave even if NC – harmless)
    GPIO_NUM_18,        // SCK / NSS
    GPIO_NUM_19,        // MISO
    GPIO_NUM_23,        // MOSI

    GPIO_NUM_14,        // RESET
    GPIO_NUM_26,        // DIO0
    GPIO_NUM_27,
    GPIO_NUM_33,        // DIO1
    GPIO_NUM_32,        // DIO2
    /* I²C battery gauge */
    GPIO_NUM_21,        // SDA
    GPIO_NUM_22,        // SCL
    GPIO_NUM_4          // MAX17048 ALRT
};

// Schedule TX every this many seconds
// Respect Fair Access Policy and Maximum Duty Cycle!
// https://www.thethingsnetwork.org/docs/lorawan/duty-cycle.html
// https://www.loratools.nl/#/airtime
const unsigned TX_INTERVAL = 3600;

void setup() {
    setCpuFrequencyMhz(40);
    WiFiClass::mode(WIFI_OFF);
    WiFi.disconnect(true);
    esp_wifi_stop();
    esp_bt_controller_disable();
    btStop();
    gpio_deep_sleep_hold_dis();
    gpio_hold_dis(static_cast<gpio_num_t>(VCC_ENA_PIN));
    for (gpio_num_t p : AUX_PINS) {
        gpio_hold_dis(p);
    }
    pinMode(VCC_ENA_PIN, OUTPUT);
    digitalWrite(VCC_ENA_PIN, HIGH);
    gpio_hold_dis((gpio_num_t)VCC_ENA_PIN);
    delay(100);
    pinMode(START_WEB_CONFIG_PIN, INPUT);
    Wire.begin(21, 22);
    delay(200);        // Longer delay to ensure I2C bus is stable
    Serial.begin(115200);

    // Print firmware version information at startup
    version::printFirmwareVersion();

    adc_power_acquire();
    randomSeed(analogRead(0));

    // Initialize the MAX17048 battery gauge first
    if (maxlipo.begin()) {
        maxLipoFound = true;
        Serial.println(FPSTR(msg_lipo_gauge_found));

        // Now it's safe to wake and configure the gauge
        maxlipo.wake();
        maxlipo.sleep(false);
    } else {
        Serial.println(FPSTR(msg_no_max14048));
    }
    FastLED.addLeds<WS2812B, LED_DATA_PIN, GRB>(leds, NUM_LEDS);
    FastLED.setBrightness(50);
    lorawan_preferences_init();
    Serial.print(FPSTR(msg_lmic_config_present));
    Serial.print("Button pin raw value: ");
    int pinValue = digitalRead(START_WEB_CONFIG_PIN);
    Serial.println(pinValue);
    startWebConfig = (pinValue == 0);        // Explicitly check for LOW
    Serial.print("startWebConfig set to: ");
    Serial.println(startWebConfig ? 1 : 0);
    bool otaa_cfg = settings_has_key("ttn_otaa_config");
    Serial.print("WEBCONF: ");
    if (startWebConfig) {
        Serial.println("true");
    } else {
        Serial.println("false");
    }
    if ((startWebConfig == true) || (!otaa_cfg)) {
        setCpuFrequencyMhz(80);
        Serial.updateBaudRate(115200);
        WiFi.disconnect(false);
        resetLmic();
        startWebConf();
    }

    PrintLMICVersion();
    // LMIC init
    os_init();

    LMIC_reset();
    if (!lmic_init_needed()) {
        Serial.println(FPSTR(msg_lmic_data_found));
        load_lmic();
    }

    LoraWANDebug(LMIC);

    // Start job (sending automatically starts OTAA too)
    LMIC_selectSubBand(1);

    do_send(&sendjob);
    entry = millis();
}

void loop() {
    static unsigned long lastPrintTime = 0;
    os_runloop_once();
    const bool timeCriticalJobs =
        os_queryTimeCriticalJobs(ms2osticksRound((TX_INTERVAL * 1000)));

    // Check if OTA is in progress - prevent sleep during OTA
    if (isOtaInProgress()) {
        Serial.println(FPSTR(msg_ota_in_progress));
        if (lastPrintTime + 1000 < millis()) {
            Serial.println(FPSTR(msg_waiting_for_ota));
            PrintRuntime();
            lastPrintTime = millis();
        }
        return;        // Don't proceed with sleep logic
    }

    if (!timeCriticalJobs && enableSleep_ == true &&
        !(LMIC.opmode & OP_TXRXPEND)) {
        Serial.print(F("Can go sleep "));
        LoraWANPrintLMICOpmode();
        lmic_save();
        GoDeepSleep();
    } else if (lastPrintTime + 1000 < millis()) {
        Serial.print(F("Cannot sleep "));
        Serial.print(F("TimeCriticalJobs: "));
        Serial.print(timeCriticalJobs);
        Serial.print(" ");

        LoraWANPrintLMICOpmode();
        PrintRuntime();
        lastPrintTime = millis();
    }
    if (millis() - entry > 60000) {
        // ToDo: Delete LMIC config from nvram
        // so it joins the wan after next run
        resetLmic();
        GoDeepSleep();
    }
}

void PrintRuntime() {
    long seconds = millis() / 1000;
    Serial.print(FPSTR(msg_runtime));
    Serial.print(seconds);
    Serial.println(FPSTR(msg_seconds));
}

[[noreturn]] void GoDeepSleep() {
    // Turn off the lipo gauge:
    //
    unsigned long long sleepTime = get_sleep_time_seconds();
    Serial.println(FPSTR(msg_going_to_deepsleep));
    Serial.println(sleepTime);
    leds[0] = CRGB::Black;
    FastLED.show();

    WiFiClass::mode(WIFI_OFF);
    WiFi.disconnect(true);
    btStop();

    // Only control MAX17048 if it was successfully initialized
    if (maxLipoFound) {
        maxlipo.hibernate();
        maxlipo.enableSleep(true);
        maxlipo.sleep(true);
    }
    LMIC_shutdown();
    Wire.end();
    SPI.end();

    for (gpio_num_t pin : AUX_PINS) {
        gpio_set_direction(pin, GPIO_MODE_INPUT);
        gpio_set_pull_mode(pin, GPIO_FLOATING);
        gpio_pullup_dis(pin);        // just in case
        gpio_pulldown_dis(pin);
        gpio_hold_en(pin);        // latch high-Z through sleep
    }

    /* -------- 2. Reset only the *always-on* GPIOs -------- */
    gpio_reset_pin(GPIO_NUM_0);
    gpio_reset_pin(GPIO_NUM_2);
    gpio_reset_pin(GPIO_NUM_12);
    gpio_reset_pin(GPIO_NUM_15);
    gpio_reset_pin(GPIO_NUM_25);
    /* AUX pins (14,26,27,32,33) are *not* reset here */

    gpio_reset_pin(GPIO_NUM_34);
    gpio_reset_pin(GPIO_NUM_35);
    gpio_reset_pin(GPIO_NUM_36);
    gpio_reset_pin(GPIO_NUM_37);
    gpio_reset_pin(GPIO_NUM_38);
    gpio_reset_pin(GPIO_NUM_39);

    adc_power_release();
    Serial.println(F("Go DeepSleep"));
    PrintRuntime();
    Serial.flush();

    esp_sleep_pd_config(ESP_PD_DOMAIN_RTC_PERIPH, ESP_PD_OPTION_OFF);
    esp_sleep_pd_config(ESP_PD_DOMAIN_RTC_SLOW_MEM, ESP_PD_OPTION_OFF);
    esp_sleep_pd_config(ESP_PD_DOMAIN_RTC_FAST_MEM, ESP_PD_OPTION_OFF);
    esp_sleep_pd_config(ESP_PD_DOMAIN_XTAL, ESP_PD_OPTION_OFF);
    save_runtime(millis() / 1000);

    digitalWrite(VCC_ENA_PIN, LOW);
    gpio_hold_en((gpio_num_t)VCC_ENA_PIN);
    delay(100);
    gpio_deep_sleep_hold_en();

    setCpuFrequencyMhz(20);
    esp_sleep_enable_timer_wakeup(sleepTime * uS_TO_S_FACTOR);
    esp_deep_sleep_start();
}

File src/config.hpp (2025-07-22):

#pragma once

// Centralised configuration constants for the project.
//
// Moving all compile–time configuration into this header makes it easier to
// maintain different hardware revisions or build variants.  Changing the
// value in a single place is enough and prevents the usual problems that come
// with duplicated literal numbers or pre-processor macros spread across the
// code base.
//
// Only constexpr variables (and not macros) are exposed here.  This gives the
// compiler type information, avoids possible name collisions and honours the
// usual C++ scoping rules.  All constants live in the `config` namespace so
// that they do not pollute the global namespace.

namespace config {

// Debug control --------------------------------------------------------------
// Debug is now compile-time disabled for optimized builds
constexpr bool EnableDebug = false;

// SX127x / LMIC wiring -------------------------------------------------------
constexpr int PinLmicNss  = 18;
constexpr int PinLmicRst  = 14;
constexpr int PinLmicDio0 = 26;
constexpr int PinLmicDio1 = 33;
constexpr int PinLmicDio2 = 32;

// LoRaWAN / payload ----------------------------------------------------------
constexpr int MaxPayloadSize = 200;        // Increased to accommodate OTA messages

// Sensors --------------------------------------------------------------------
constexpr int SoilSensorPin = 34;          // ADC1_CH6
constexpr int AirValue      = 2200;        // Dry calibration value
constexpr int WaterValue    = 380;         // Wet calibration value

// Misc -----------------------------------------------------------------------
constexpr int MaxSensorRead = 1;

// Firmware Version -----------------------------------------------------------
// The FIRMWARE_VERSION is set by the CI/CD pipeline during compilation
// Format: 3-digit integer (e.g., 100 for v1.0.0, 110 for v1.1.0, 112 for v1.1.2)
#ifdef FIRMWARE_VERSION
constexpr int FirmwareVersionInt = static_cast<int>(FIRMWARE_VERSION);
#else
constexpr int FirmwareVersionInt = 0;        // Development build
#endif

}        // namespace config

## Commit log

2025-02-02 ADD: Assembley pictures
2025-02-02 ADD: Board and Code
    [MAX17048G_T10.step, RFM95 LoRa v15.step, board-mount.stl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]
2025-02-02 FIX: Link to esp32 preferences lib
2025-02-04 The battery was drained too fast due AUX power rail not deactivated
    The code reseted the VCC_ENA_PIN state, pulling it to high when going to
    sleep. I noticed the battery was draining too fast, ideally the board
    should consume a few micro amperes when going to deep sleep.
    After viewing the battery burn graph something didn't made sense, so I
    power profiled the board and I found that in deep sleep mode the board
    was consuming around 60 - 70 mA.
    I traced this to the GPIO that controlled the V_AUX rail being held high
    when deep sleep.
    The fix was to add gpio_hold_en + gpio_deep_sleep_hold_en before goint
    to sleep.
    After the firmware fix the board consumes an average of 703 mA and some
    spikes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
    [main.cpp]
2025-02-05 IMPROVED: power usage, a reduction in 50% power req.
    Before this changes the board required 31mA in average and a max of
    304mA during runtime and 703uA during deep sleep.
    After this changes the board uses: 14.85mA in active with a max of 254mA
    and during hybernation: 313uA.
2025-03-02 ADD: sonar job
2025-03-02 TEST: sonarqube gh action
2025-03-04 TEST: sonarcloud
2025-03-04 Set sonar sources
2025-07-09 FIX: sonarqube code smells and use safe string copy functions
    [lorawan.cpp, menu.cpp]
2025-07-10 FIX: sonarqube findings
2025-07-10 FIX: regresion in getArtEUDI
    [lorawan.cpp]
2025-07-11 ADD: script to get sonar issues
2025-07-11 fix: Address SonarQube critical and high-priority issues
    - Converted all #define macros to constexpr constants in main.cpp, lorawan_settings.hpp, and menu.hpp
    - Improved type safety and compile-time evaluation
    - Made global constants const across all source files
    - Enhanced immutability and thread safety
    - Replaced new/delete with std::unique_ptr in menu.cpp
    - Improved memory management and RAII compliance
    - Added explicit type conversions in lorawan.cpp
    - Prevented precision loss and type safety issues
    - Removed unused parameters from function signatures
    - Cleaned up function interfaces
    - Added [[noreturn]] attribute to GoDeepSleep() function
    - Improved compiler optimization opportunit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
    [config.hpp, lorawan.cpp, main.cpp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]
2025-07-13 FIX: ota and other stuff
    [main.cpp, menu.cpp, ota.cpp]
2025-07-15 Fixed RX of chunked data
    [lorawan.cpp, ota.cpp]
2025-07-16 feat: comprehensive size optimization achieving 90KB reduction
    Size Optimization Summary:
    - Before: 1,302,037 bytes (99.3% Flash usage)
    - After: 1,211,449 bytes (92.4% Flash usage)
    - Reduction: 90,588 bytes (~90KB)
    Changes Made:
    1. Added size-optimization compiler flags: -Os, -ffunction-sections, -fdata-sections, -Wl,--gc-sections
    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
2025-07-16 feat: add build documentation and update README with size optimization info
    - Create docs/BUILD.md with build types and optimization tips
    - Update README.md with size-saving tips and current build sizes
    - Document 90KB size reduction achievement
    - Fix skip_size_check.py script for proper operation
2025-07-22 Fix base64 decoder in OTA signature verification
    The previous base64_decode implementation had critical flaws:
    - Incorrect loop logic causing buffer overruns
    - Did not properly handle padding characters (=)
    - Would fail to decode standard base64 strings correctly
    This fix:
    - Properly handles base64 padding
    - Correctly bounds-checks array access
    - Follows standard base64 decoding algorithm
    - Should resolve Ed25519 signature verification failures
    Resolves the signature verification issue where chunked MQTT
    payloads were successfully received but signatures failed
    to verify due to incorrect base64 decoding of the signature.
    [ota.cpp]
2025-07-22 Add watchdog resets during firmware download to prevent timeout
    The device was crashing with task watchdog timeout during firmware
    download because the WiFi task would take too long without resetting
    the watchdog timer.
    - Adds esp_task_wdt_reset() calls every 512 bytes during download
    - Includes progress reporting every 10KB
    - Should prevent watchdog timeouts during large firmware downloads
    The signature verification is now working correctly with the previous
    base64 decoder fix.
    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
    [ota.cpp]
2025-07-22 Enable HTTP redirects for URL shortener support
    The HTTPClient was not following redirects from URL shorteners like
    TinyURL, causing it to try to download the redirect HTML page instead
    of the actual firmware binary.
    - Enables HTTPC_STRICT_FOLLOW_REDIRECTS
    - Sets redirect limit to 10 hops
    - Adds better logging of HTTP responses and redirects
    - Should resolve watchdog timeouts caused by downloading wrong content
    This addresses the issue where signature verification succeeds but
    firmware download fails due to redirect handling.
    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
    [ota.cpp]
2025-07-22 Add comprehensive WiFi debugging and improved connection handling
    The device was crashing without showing any WiFi connection attempts,
    suggesting potential issues with WiFi setup or settings retrieval.
    This fix adds:
    - Detailed logging of WiFi credentials from settings
    - Proper WiFi state reset before attempting connection
    - Extended connection timeout (30 attempts vs 20)
    - WiFi status codes and connection details logging
    - Regular watchdog resets during WiFi connection attempts
    - Network information display upon successful connection
    - Better error reporting for troubleshooting
    This should help identify whether the issue is:
    1. Missing WiFi credentials in settings
    2. WiFi connection fail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
    [ota.cpp]
2025-07-23 Add LMIC suspension during WiFi operations to prevent interference
    The watchdog crash was happening right after WiFi.mode(WIFI_STA)
    because LoRaWAN (LMIC) and WiFi were conflicting for radio resources.
    - Includes proper LMIC headers and references
    - Suspends LMIC operations before enabling WiFi
    - Sets OP_SHUTDOWN flag to temporarily disable LMIC
    - Clears any pending sendjob callbacks
    - Allows clean transition from LoRaWAN to WiFi mode
    This should resolve the immediate crash after 'Enabling WiFi in STA mode'
    and allow the WiFi connection to proceed normally.
    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
    [ota.cpp]
2025-07-23 Fix OTA watchdog handling and update documentation
    [ota.cpp]
2025-07-23 Fix OTA stack overflow and watchdog timeout issues
    - Replace stack-allocated 4KB buffer with heap-allocated 2KB buffer to prevent stack overflow
    - Increase watchdog reset frequency from 2s to 1s during OTA downloads
    - Add proper memory cleanup and error handling for heap-allocated buffer
    - Update documentation to reflect stack overflow prevention measures
    - Resolves Guru Meditation Error: Stack canary watchpoint triggered
    [ota.cpp]
2025-07-23 Improve OTA HTTP timeout handling and connectivity diagnostics
    - Add explicit HTTP timeout configuration (30s total, 15s connection)
    - Add internet connectivity test before OTA download using httpbin.org
    - Improve timeout handling for better network reliability
    - Add diagnostic output for troubleshooting network issues
    - Maintain graceful failure handling with proper error reporting
    [ota.cpp]
2025-07-23 Add debug output to diagnose OTA URL parsing issues
    - Add JSON string and length debug output
    - Add extracted URL debug output
    - Help identify where URL truncation is occurring
    - Temporary debug code to resolve parsing discrepancy
    [ota.cpp]
2025-07-23 Increase OTA buffer sizes and add debug output for chunked messages
    - Increase OTA_MAX_CHUNKS from 20 to 30
    - Increase OTA_CHUNK_SIZE from 70 to 100 bytes
    - Add debug output to track chunk reception and assembly
    - This should resolve JSON truncation issues during OTA updates
    [ota.cpp]
2025-07-24 feat: integrate ESP32 HTTPUpdate library for improved OTA reliability
    - Replace custom HTTP download implementation with ESP32's built-in HTTPUpdate library
    - Add automatic HTTPS support with certificate validation bypass for simplicity
    - Implement built-in MD5 verification via x-MD5 header
    - Add comprehensive progress monitoring with watchdog management
    - Improve error handling and cleanup
    - Enable strict HTTP redirect following
    - Remove large buffer allocation - HTTPUpdate handles streaming internally
    - Update documentation to reflect HTTPUpdate integration improvements
    This change significantly improves OTA reliability by leveraging the well-tested
    ESP32 HTTPUpdate library while maintain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
    [ota.cpp]
2025-07-24 fix: improve OTA robustness with memory diagnostics and error handling
    - Add comprehensive memory diagnostics before OTA starts
    - Check for minimum 32KB heap memory before attempting OTA
    - Add try-catch error handling around HTTPUpdate.update() call
    - Force memory cleanup with delay before OTA start
    - Add detailed memory status logging for debugging
    - Improve error reporting for OTA partition erase failures
    This addresses potential flash erase crashes by ensuring sufficient memory
    is available and providing better error handling during the OTA process.
    [ota.cpp]
2025-07-24 fix: change to OTA-compatible partition table (min_spiffs.csv)
    - Replace huge_app.csv with min_spiffs.csv partition table
    - Provides dual app partitions (app0/app1) required for OTA updates
    - Each app partition: 1.875MB (sufficient for ~1.33MB firmware)
    - Fixes esp_flash_erase_region crashes due to single app partition
    - Current firmware: 67.8% of available app partition space
2025-07-24 fix: update GitHub Actions flash size limits for OTA partition table
    - Increase flash size limit from 1.3MB to 1.8MB (90% of 1.875MB app partition)
    - Accounts for min_spiffs.csv partition table with dual OTA app partitions
    - Current firmware (~1.34MB) now passes size checks with headroom
    - Updated all three pipeline stages: branch, main, and release
